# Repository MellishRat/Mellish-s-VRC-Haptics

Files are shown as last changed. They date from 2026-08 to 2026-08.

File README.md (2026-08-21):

# Mellish's VRC Haptics

ESP32 haptic-controller projects for Intiface and OscGoesBrrr. Start with the
completed two-channel build unless you specifically want to develop and test
the experimental PCA9685 design.

| Project | Status | Description |
|---|---|---|
| [Mellish Edge-Compatible Two-Motor Emulator](projects/edge-2-channel/README.md) | **Stable and verified** | Hardware-verified ESP32 build with two independent `0–20` Intiface vibration outputs on GPIO25 and GPIO26. |
| [Mellish 16-Channel Haptic Controller — Experimental](projects/mellish-16-channel/README.md) | **Experimental** | PCA9685 development area. Channels 0 and 1 map to the two currently exposed Edge-compatible outputs; custom 4–16-output Intiface support is future work. |

## Recommended starting point

Build the [stable two-channel project](projects/edge-2-channel/README.md) first.
It contains the verified firmware, wiring guidance, phone/PC connection steps,
troubleshooting notes, and the proposed `edge-2ch-v1.0.0` release notes.

The [16-channel project](projects/mellish-16-channel/README.md) is intentionally
kept separate so experimental PCA9685 work cannot be confused with the verified
direct-GPIO firmware.

## Shared images

Component reference photographs are retained in [`images/`](images/README.md).
Project-specific wiring diagrams live with each project.

## Safety

Never drive a motor directly from an ESP32 GPIO. Use a suitably rated driver or
MOSFET, a correctly rated regulated motor supply, appropriate protection, and a
common ground. Disconnect motor power before changing wiring.

## License

Licensed under the [MIT License](LICENSE).

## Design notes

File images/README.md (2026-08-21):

# Shared component photographs

These photographs are component references, not wiring diagrams. Always follow
the printed pin labels and the relevant project's wiring guide.

| Component | Photograph |
|---|---|
| ESP32-WROOM-32 development board | [esp32-wroom-32-dev-board.jpg](esp32-wroom-32-dev-board.jpg) |
| SSD1306 128×32 OLED | [ssd1306-128x32-oled.jpg](ssd1306-128x32-oled.jpg) |
| Small vibration motor module | [vibration-motor-module.jpg](vibration-motor-module.jpg) |
| DollaTek PCA9685 16-channel 12-bit PWM board | [DollaTek PCA9685 16 Channel 12-bit PWM.jpg](DollaTek%20PCA9685%2016%20Channel%2012-bit%20PWM.jpg) |

The shared editable Fritzing project is available as
[`layout.fzz`](layout.fzz). It contains the breadboard layouts for both the
stable two-channel build and the experimental 16-channel controller. Open it
with Fritzing to inspect or modify the layouts, and follow the applicable
project's wiring and safety guidance before building or applying power.

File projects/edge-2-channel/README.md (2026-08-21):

# Mellish Edge-Compatible Two-Motor Emulator

**Status: completed and hardware verified. Recommended starting point.**

This ESP32-WROOM-32 project emulates a Lovense Edge over Bluetooth Low Energy.
Its verified firmware identifies with Lovense model identifier `P`, and Intiface
exposes it as two independent vibration outputs with levels from `0` to `20`.
It is an Edge-compatible two-motor emulator; it is not described as a verified
Gemini emulator.

## Verified hardware and behaviour

- ESP32-WROOM-32 development board (`ESP32 Dev Module`)
- SSD1306 128×32 OLED at I²C address `0x3C`
- OLED SDA on GPIO21 and SCL on GPIO22
- Motor 1 control signal on GPIO25
- Motor 2 control signal on GPIO26
- `MOTOR1_MIN_PWM` = `70`
- `MOTOR2_MIN_PWM` = `75`
- OLED BLE connection status and two motor-level bars
- automatic BLE advertising restart after disconnect
- immediate motor-off disconnect failsafe
- Arduino ESP32 Core 2.x and 3.x PWM API compatibility
- two independent Intiface vibration outputs

The tested signal path is:

```text
VRChat on PC → OscGoesBrrr on PC → Intiface on phone → BLE → ESP32
```

The phone and PC communicate over the local network. The ESP32 itself uses BLE
only: it needs no Wi-Fi credentials and runs no WebSocket server.

## Build and upload

1. Install the Espressif ESP32 Arduino board package.
2. Select **ESP32 Dev Module**.
3. Install **Adafruit GFX Library** and **Adafruit SSD1306**.
4. Open [`firmware/Mellish_Edge_2_Channel/Mellish_Edge_2_Channel.ino`](firmware/Mellish_Edge_2_Channel/Mellish_Edge_2_Channel.ino).
5. Upload, then open Serial Monitor at `115200` baud.
6. Follow the [Intiface and OscGoesBrrr instructions](docs/intiface-setup.md).

The sketch folder and `.ino` filename match, as required by Arduino.

## Documentation

- [Architecture, BLE identity, and protocol](docs/architecture.md)
- [Wiring, pinout, and external motor drivers](wiring/README.md)
- [Shared editable Fritzing layouts](../../images/layout.fzz)
- [Intiface on phone and OscGoesBrrr on PC](docs/intiface-setup.md)
- [VRChat integration](docs/vrchat-setup.md)
- [Troubleshooting](docs/troubleshooting.md)
- [Hardware-verification checkpoint](docs/verified-checkpoint.md)
- [Proposed `edge-2ch-v1.0.0` release notes](docs/release-notes-edge-2ch-v1.0.0.md)

## Safety

GPIO25 and GPIO26 are control signals only. Never connect a motor directly to
an ESP32 GPIO. See the [wiring guide](wiring/README.md) before applying motor
power.

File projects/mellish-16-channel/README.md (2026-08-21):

# Mellish 16-Channel Haptic Controller — Experimental

**Status: experimental; not a replacement for the verified two-channel build.**

This development area moves motor PWM generation to a PCA9685 at I²C address
`0x40`. The PCA9685 shares the ESP32's GPIO21/GPIO22 I²C bus with the SSD1306
OLED at `0x3C`.

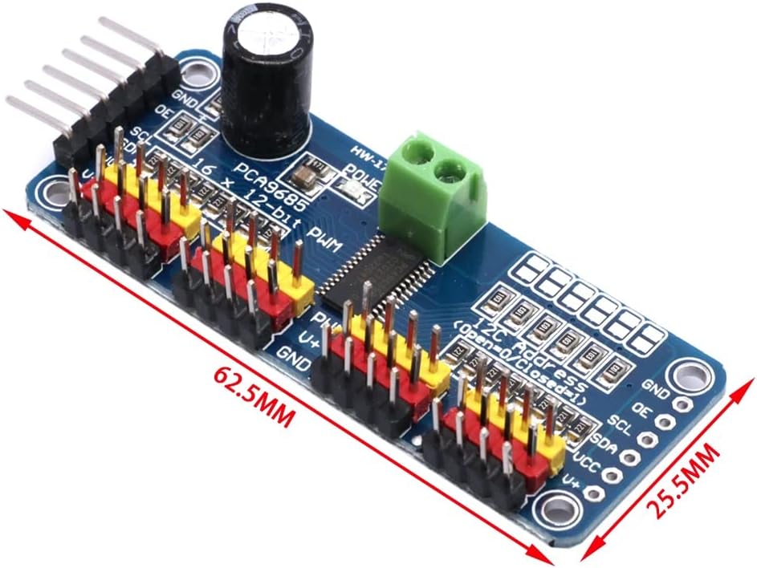
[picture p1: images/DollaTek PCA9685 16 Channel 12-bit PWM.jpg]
DollaTek PCA9685 16-channel 12-bit PWM board


The photograph is a component reference. The shared editable
[Fritzing project](../../images/layout.fzz) contains layouts for both repository
projects; select the 16-channel layout here, verify the actual board labels and the
[wiring guide](wiring/README.md) before applying power.

The current firmware still identifies as a Lovense Edge. Intiface therefore
exposes only two vibration outputs: output 0 controls PCA9685 channel 0 and
output 1 controls PCA9685 channel 1. Custom 4–16-output Intiface support is
future experimental work; channels 2–15 are not independently addressable from
Intiface yet.

## Current experimental features

- PCA9685 PWM controller at I²C address `0x40`
- SSD1306 OLED and PCA9685 sharing SDA GPIO21 and SCL GPIO22
- PCA9685 logic VCC powered from ESP32 3.3 V
- separate motor power entering at PCA9685 `V+` and `GND`
- all grounds connected in common
- Intiface outputs 0 and 1 mapped to PCA9685 channels 0 and 1
- Serial Monitor `TEST` command pulses channels 0–15 sequentially
- Serial Monitor `STOP`, Lovense `PowerOff;`, and BLE disconnect switch every channel off

## Firmware

Open
[`firmware/Mellish_16_Channel_Experimental/Mellish_16_Channel_Experimental.ino`](firmware/Mellish_16_Channel_Experimental/Mellish_16_Channel_Experimental.ino).
The sketch folder and `.ino` filename match.

Required Arduino libraries:

- Adafruit GFX Library
- Adafruit SSD1306
- Adafruit PWM Servo Driver Library
- BLE support supplied by the Espressif ESP32 Arduino core

## Documentation

- [Experimental scope and protocol](docs/architecture.md)
- [PCA9685 wiring and power guidance](wiring/README.md)
- [Shared editable Fritzing layouts](../../images/layout.fzz)
- [Development and test procedure](docs/testing.md)

For a known-good build, use the
[Mellish Edge-Compatible Two-Motor Emulator](../edge-2-channel/README.md).

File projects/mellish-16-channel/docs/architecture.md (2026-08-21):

# Experimental architecture

```text
Intiface output 0 → Lovense Vibrate1 → PCA9685 channel 0
Intiface output 1 → Lovense Vibrate2 → PCA9685 channel 1
Serial TEST command                 → channels 0–15 in sequence
```

The ESP32 currently retains the Lovense Edge BLE identity and model identifier
`P`. This deliberately preserves the established two-output Intiface path while
PCA9685 output hardware is developed. It does **not** make 16 outputs available
to Intiface. A future experimental protocol/device definition is required for
custom 4–16-output support.

The PCA9685 handles PWM for all motor-control channels. The stable project's
direct GPIO25/GPIO26 motor PWM implementation is not used in this sketch.

`STOP`, Lovense `PowerOff;`, and Bluetooth disconnect call the all-channel-off
path. BLE advertising restarts after disconnect.

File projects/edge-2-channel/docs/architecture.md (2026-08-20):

# Architecture and protocol

## Runtime architecture

```mermaid
sequenceDiagram
    participant V as VRChat (PC)
    participant O as OscGoesBrrr (PC)
    participant I as Intiface Central (phone)
    participant E as ESP32
    V->>O: OSC contact/avatar values
    O->>I: Buttplug commands via ws://phone-ip:12345
    I->>E: Lovense commands over BLE
    E->>E: Map output 0/1 to GPIO25/26 PWM
    E-->>I: DeviceType, Battery, Status responses
```

The ESP32 does not parse VRChat OSC. OGB interprets VRChat data and controls
Intiface. Intiface translates Buttplug output commands into Lovense BLE traffic.

## BLE identity

| Property | Value |
|---|---|
| Advertised name | `LVS-Edge` |
| Emulated model | Lovense Edge (`P`) |
| Stable logical address | `MELLISH-HAPTICS-001` |
| BLE service | `50300001-0023-4bd4-bbd5-a6920e4c5653` |
| Command/write characteristic | `50300002-0023-4bd4-bbd5-a6920e4c5653` |
| Response/read-notify characteristic | `50300003-0023-4bd4-bbd5-a6920e4c5653` |

The firmware uses a stable locally administered base MAC. This deliberately
differs from the address used by the earlier BLE diagnostic sketch, preventing
Android from reusing a stale bonded GATT-service cache.

## Lovense commands

| Command | Firmware behavior |
|---|---|
| `DeviceType;` | Replies `P:1:MELLISH-HAPTICS-001;` |
| `Battery;` | Replies `100;` (wired prototype placeholder) |
| `Status:1;` | Replies `2;` |
| `Vibrate1:n;` | Sets Motor 1 / GPIO25, with `n` clamped to 0–20 |
| `Vibrate2:n;` | Sets Motor 2 / GPIO26, with `n` clamped to 0–20 |
| `Vibrate:n;` | Compatibility fallback that sets both motors |
| `PowerOff;` | Stops both motors and replies `OK;` |

## Calibrated PWM mapping

Level 0 always produces PWM 0. Levels 1–20 are linearly mapped from each
motor's independent minimum usable PWM to 255.

| Lovense level | Motor 1 PWM (minimum 70) | Motor 2 PWM (minimum 75) |
|---:|---:|---:|
| 0 | 0 | 0 |
| 1 | 70 | 75 |
| 10 | 157 | 160 |
| 20 | 255 | 255 |

## Safety behavior

- Both outputs start at zero.
- BLE disconnection immediately sets both outputs to zero.
- Values are clamped to the Lovense 0–20 range.
- Each channel updates independently for `Vibrate1` and `Vibrate2`.
- The OLED is optional; failure to detect it does not disable the motor
  failsafe or Serial diagnostics.

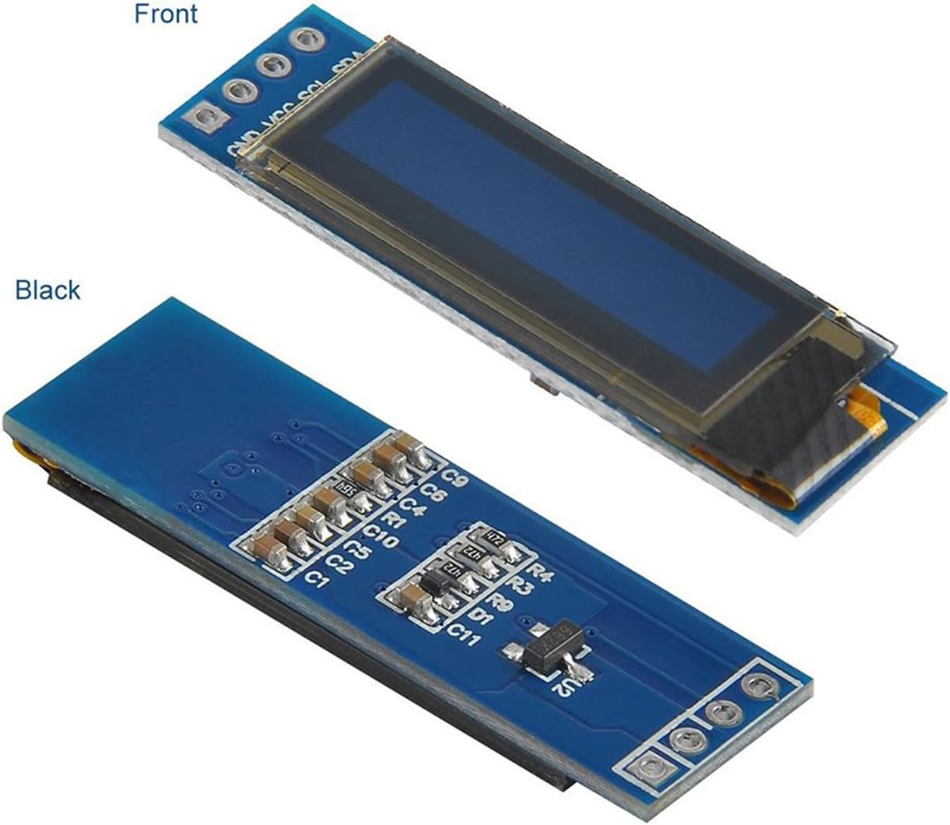
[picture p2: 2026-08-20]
images/ssd1306-128x32-oled.jpg

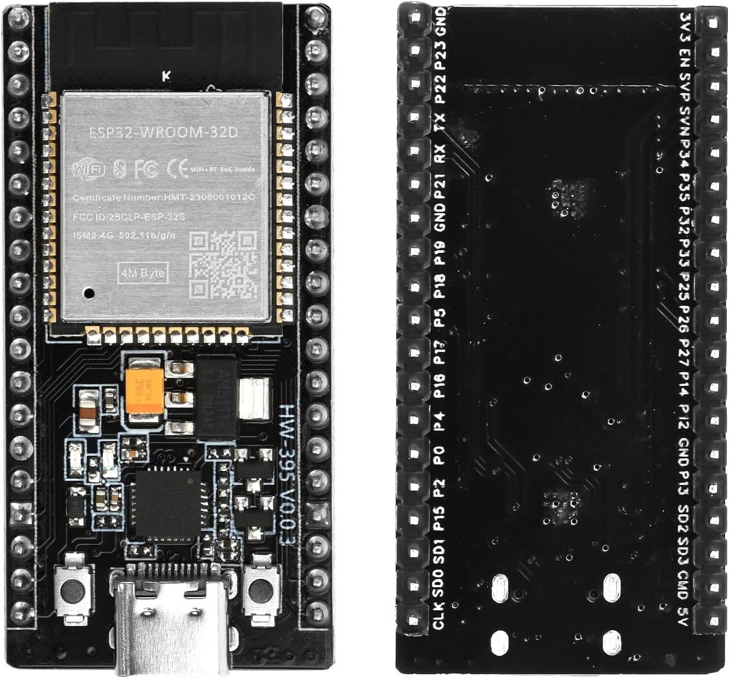
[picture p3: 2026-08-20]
images/esp32-wroom-32-dev-board.jpg

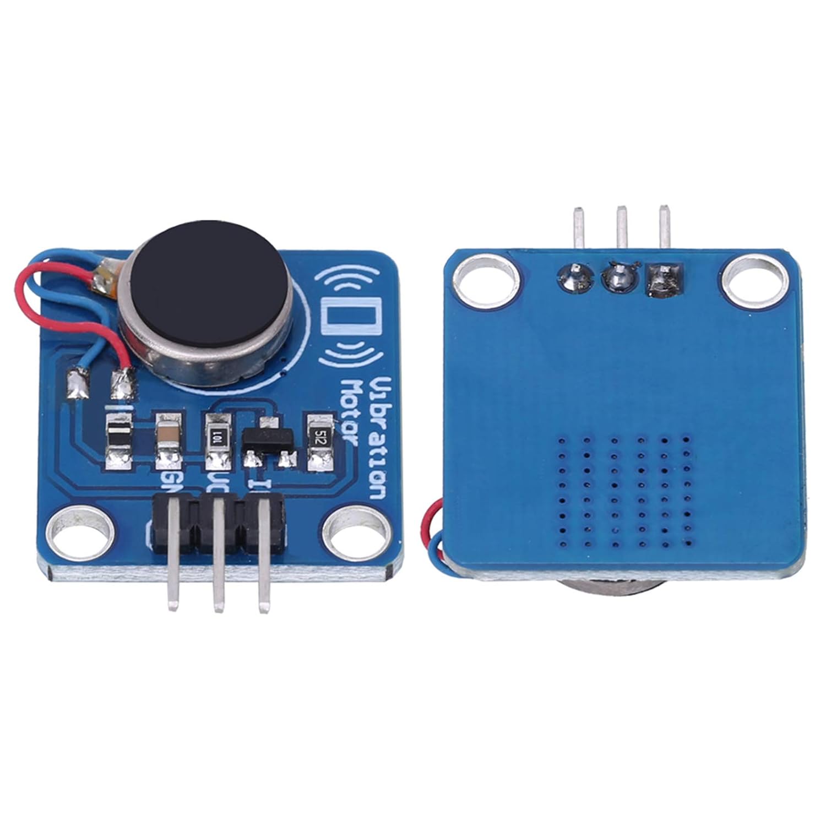
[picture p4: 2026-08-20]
images/vibration-motor-module.jpg

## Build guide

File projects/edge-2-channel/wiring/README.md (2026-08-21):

# Two-channel wiring and pinout

## Layout files

- [Open or download the shared editable Fritzing project](../../../images/layout.fzz)
- [View the rendered two-motor breadboard diagram](two-motor-breadboard.png)

The Fritzing project contains layouts for both repository projects. Select the
stable two-channel layout for this build and verify all physical pin labels
against the connection table below before applying power.

## Connections

| ESP32 connection | Destination | Purpose |
|---|---|---|
| GPIO21 | OLED SDA | I²C data |
| GPIO22 | OLED SCL | I²C clock |
| 3.3 V | OLED VCC | OLED power |
| GND | OLED GND | Common ground |
| GPIO25 | Motor 1 driver input | PWM control for Intiface output 0 |
| GPIO26 | Motor 2 driver input | PWM control for Intiface output 1 |
| GND | Both motor-driver grounds | Common signal/power reference |
| Rated motor supply + | Both driver motor-power inputs | Motor power appropriate to the motor modules |

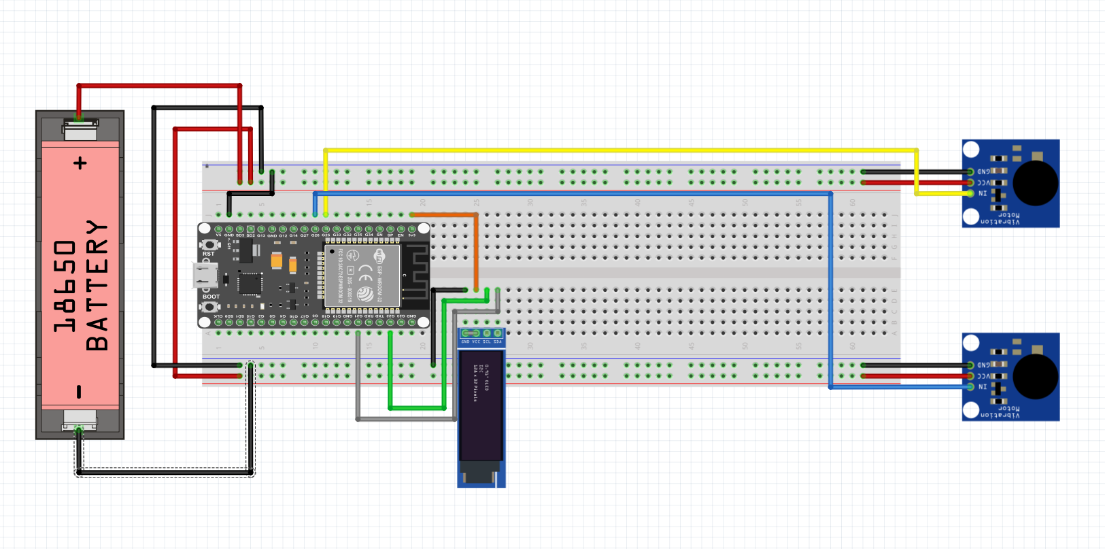
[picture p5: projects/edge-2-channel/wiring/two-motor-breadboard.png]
Two-motor breadboard wiring diagram


The diagram is a build reference; verify every physical module's printed pin
labels before applying power. Shared component photographs are in the
[repository image gallery](../../../images/README.md).

## Larger motors and external controllers

Each GPIO signal may control the logic input of a suitably rated external
MOSFET circuit or motor controller instead of the small motor module. GPIO25
and GPIO26 must remain signal connections only—never drive any motor directly
from an ESP32 GPIO.

Larger motors require their own correctly rated regulated supply, a driver with
adequate voltage/current and thermal ratings, and appropriate protection such
as flyback suppression where the chosen motor/driver requires it. Connect the
external supply ground, controller ground, and ESP32 ground together so the
control signals have a common reference. Confirm that the controller accepts
3.3 V logic.

## Electrical checks

1. Disconnect motor power before changing wiring.
2. Confirm both driver inputs accept 3.3 V logic and are active high.
3. Confirm the supply supports both motors' startup current simultaneously.
4. Join the motor-supply negative terminal to ESP32 GND.
5. Initially test each channel separately at levels `0` and `1`.
6. Stop immediately if the ESP32 resets, the OLED glitches, or anything heats.

The verified firmware uses active-high 20 kHz, 8-bit PWM.

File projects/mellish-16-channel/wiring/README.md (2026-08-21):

# PCA9685 experimental wiring

## Layout files

- [Open or download the shared editable Fritzing project](../../../images/layout.fzz)
- [View the PCA9685 component photograph](../../../images/DollaTek%20PCA9685%2016%20Channel%2012-bit%20PWM.jpg)

The Fritzing file contains layouts for both repository projects. Select the
experimental 16-channel layout here. It is an editable layout aid, not a
substitute for checking the labels and electrical ratings on the physical
modules. The textual connection table and safety requirements below are
authoritative for this project.

## I²C and logic connections

| ESP32 | OLED | PCA9685 | Purpose |
|---|---|---|---|
| 3.3 V | VCC | VCC | Logic power |
| GND | GND | GND | Common reference |
| GPIO21 | SDA | SDA | Shared I²C data |
| GPIO22 | SCL | SCL | Shared I²C clock |

- OLED address: `0x3C`
- PCA9685 address: `0x40`
- PCA9685 `VCC` must be powered from ESP32 3.3 V.
- Motor power enters through PCA9685 `V+` and `GND`, not through `VCC`.
- ESP32, OLED, PCA9685, motor supply, and motor drivers must share a common ground.

```text
ESP32 3V3 ──┬── OLED VCC
            └── PCA9685 VCC (logic)
ESP32 GND ──┬── OLED GND
            ├── PCA9685 GND
            └── regulated motor-supply negative
GPIO21 ─────┬── OLED SDA
            └── PCA9685 SDA
GPIO22 ─────┬── OLED SCL
            └── PCA9685 SCL

regulated motor-supply positive ── PCA9685 V+
PCA9685 channels 0–15 ──────────── suitable motor modules/controllers
```

## Motor modules and supply sizing

The small motor modules are specified for `3.0–5.3 V`, `60 mA` running current,
and `90 mA` starting current. Sixteen motors may demand about `1.44 A` at startup
before allowing for margin, controller losses, wiring losses, or supply
tolerance. Use a properly rated regulated supply selected for the actual motors
and simultaneous startup load.

Do not route the full 16-motor current through solderless breadboard power rails.
Use appropriately rated distribution wiring, connectors, protection, motor
drivers, and decoupling. Never drive a motor from an ESP32 GPIO or assume a bare
PCA9685 output can supply motor current; each PWM channel must feed a suitable
motor-driver or MOSFET input.

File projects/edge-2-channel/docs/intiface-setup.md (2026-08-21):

# Intiface and OscGoesBrrr setup

## Intiface on the phone

1. Start the Intiface engine.
2. Start a normal Bluetooth device scan in Intiface.
3. Wait for `LVS-Edge` to be discovered and initialized.
4. Confirm the Devices page shows a Lovense Edge with two vibration outputs.

Expected ESP32 Serial output:

```text
BLE advertising as: LVS-Edge
BLE CONNECTED to Intiface
BLE RX: DeviceType;
BLE TX: P:1:MELLISH-HAPTICS-001;
```

Android's normal Bluetooth settings may not list this BLE-only peripheral. The
Intiface scan is authoritative. Do not manually bond the ESP32.

The ESP32 connects only by BLE. It does not need the phone's IP address, Wi-Fi
credentials, or any custom WebSocket-device entry.

## OscGoesBrrr on the PC

With Intiface running on the phone, configure OGB to connect to the phone's LAN
address, for example:

```text
ws://192.168.0.251:12345
```

The actual phone IP can change with DHCP. The ESP32 does not use this address;
only OGB needs it. The verified test used OscGoesBrrr v2.1.28.

## First output test

Before involving VRChat:

1. Set both outputs to 0.
2. Exercise output 0 through `0 → 1 → 10 → 20 → 0`; Motor 2 must remain still.
3. Exercise output 1 through the same sequence; Motor 1 must remain still.
4. Disconnect Intiface and confirm both motors stop immediately.

Expected PWM values are documented in [architecture.md](architecture.md).

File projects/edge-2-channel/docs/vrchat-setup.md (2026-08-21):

# VRChat integration

First confirm the completed two-channel build using Intiface's independent
output controls, then configure the VRChat-specific mapping.

## Planned data path

```text
VRCFury/SPS Touch Zones → VRChat OSC → OscGoesBrrr → Intiface → BLE ESP32
```

Use VRCFury SPS Touch Zones with OGB IDs such as `VB01` and `VB02`. OGB should
map those sources to the two features of the single Edge-compatible device:

```text
VB01 → output 0 → GPIO25 → Motor 1
VB02 → output 1 → GPIO26 → Motor 2
```

The firmware intentionally has no knowledge of body-part names. All semantic
mapping belongs in the avatar/OGB configuration.

The BLE device, two Intiface outputs, and independent physical motor response
are hardware verified. OGB IDs and avatar contact placement are configured per
avatar and are not embedded in the firmware.

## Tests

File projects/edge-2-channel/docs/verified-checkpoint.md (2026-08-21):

# Hardware-verified checkpoint — 20 August 2026

## Verified

- ESP32-WROOM-32 uploads and runs from the Arduino IDE.
- SSD1306 128×32 OLED works on GPIO21/GPIO22 at `0x3C`.
- GPIO25 and GPIO26 independently control the two motor driver modules.
- ESP32 Bluetooth radio advertising and GATT connection work.
- Intiface on Android discovers `LVS-Edge` over BLE.
- Intiface identifies it as a Lovense Edge.
- The device populates in Intiface with two vibration outputs.
- Intiface controls the two physical motors independently across the `0–20` range.
- Motor 1 has a verified minimum PWM of `70`; Motor 2 has a verified minimum PWM of `75`.
- OGB v2.1.28 connects from the PC to Intiface on the phone over the LAN.
- BLE disconnect invokes the firmware motor-off failsafe.

The ESP32/Intiface two-channel build is complete and hardware verified. Avatar
contact placement and OscGoesBrrr source bindings remain user-specific setup,
not unverified firmware behaviour.

## Important diagnostic result

The initial BLE radio test and haptics firmware shared a Bluetooth address,
causing Android to reuse the diagnostic sketch's cached GATT table. The current
firmware assigns a separate stable locally administered base MAC, ensuring that
Android discovers the correct Lovense service and characteristics.

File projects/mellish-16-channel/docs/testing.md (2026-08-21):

# Experimental test procedure

1. Disconnect motor power and verify the wiring against the
   [PCA9685 wiring guide](../wiring/README.md).
2. Upload the experimental sketch and open Serial Monitor at `115200` baud.
3. Confirm the OLED is found at `0x3C` and the PCA9685 at `0x40`.
4. With a current-limited, correctly rated motor supply connected to `V+` and
   `GND`, enter `TEST` in Serial Monitor.
5. Confirm channels 0 through 15 pulse one at a time and return off.
6. Enter `STOP` at any time to switch every channel off.
7. In Intiface, confirm output 0 affects only PCA9685 channel 0 and output 1
   affects only channel 1.
8. Disconnect Bluetooth and confirm all channels switch off immediately.

The `TEST` command is a bench diagnostic, not an Intiface 16-output interface.

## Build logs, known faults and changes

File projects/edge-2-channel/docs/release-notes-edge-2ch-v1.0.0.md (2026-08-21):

# Proposed release notes: `edge-2ch-v1.0.0`

> Proposed only. No release or Git tag has been created.

## Mellish Edge-Compatible Two-Motor Emulator v1.0.0

First stable, hardware-verified release of the two-channel ESP32 haptic controller.

### Highlights

- Lovense Edge BLE emulation using model identifier `P`
- two independent Intiface `0–20` vibration outputs
- GPIO25 Motor 1 and GPIO26 Motor 2 PWM control
- independent calibrated minimum PWM values of `70` and `75`
- SSD1306 128×32 OLED status and motor-level bars on GPIO21/GPIO22 at `0x3C`
- automatic advertising restart after BLE disconnect
- immediate all-motors-off disconnect failsafe
- Arduino ESP32 Core 2.x/3.x PWM compatibility
- documented Intiface-on-phone and OscGoesBrrr-on-PC workflow

### Hardware safety

Motors must be driven through suitable motor-driver modules, MOSFET circuits,
or controllers. Never drive a motor directly from an ESP32 GPIO. Use a
correctly rated supply, appropriate protection, and a common ground.

### Release approval

Create the `edge-2ch-v1.0.0` tag and GitHub release only after explicit owner approval.

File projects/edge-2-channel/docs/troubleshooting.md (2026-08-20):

# Troubleshooting

## Intiface sees `LVS-Edge` in logs but it is absent from Devices

Discovery is not the same as initialization. Check Serial Monitor for
`BLE CONNECTED` followed by `DeviceType;`. Leave the scan running long enough
for initialization and ensure no other app is connected to the ESP32.

## nRF Connect shows an old `12345678...` service

That UUID belongs to the temporary BLE radio-test sketch. Android has cached the
old GATT table. The current firmware uses a separate stable base MAC to avoid
that cache. Upload the latest firmware, reset the ESP32, and select the newly
advertised address. Do not bond it.

## `btleplug error: NotConnected`

- Close nRF Connect completely; only one client can hold the BLE connection.
- Remove any old ESP32 test bond.
- Toggle phone Bluetooth off and on, then reset the ESP32.
- Confirm a dedicated BLE scan sees `LVS-Edge` and service `50300001...`.

## OLED remains blank

Confirm address `0x3C`, SDA GPIO21, SCL GPIO22, 3.3 V, and common ground. The
firmware continues safely without the display and reports the failure over
Serial at 115200 baud.

## Motor does not start at level 1

Increase only that channel's minimum in steps of about five:

```cpp
const uint8_t MOTOR1_MIN_PWM = 70;
const uint8_t MOTOR2_MIN_PWM = 75;
```

Repeat `0 → 1 → 0` five to ten times. Do not change the other channel. Confirm
the other motor remains physically still and its OLED/Serial level remains 0.

## Motor is always on

Disconnect motor power. Verify `IN`, `VCC`, and `GND`, and confirm the driver is
active high. Do not compensate for incorrect wiring in software.

## ESP32 resets or OLED flickers when motors start

Treat this as a power-integrity or motor-noise problem. Use a correctly sized
supply, common ground, short wiring, and appropriate decoupling/suppression.

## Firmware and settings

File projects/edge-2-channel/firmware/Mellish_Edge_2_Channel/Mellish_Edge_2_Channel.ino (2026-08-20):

/*
  Mellish VRC Haptics - ESP32 Lovense Edge BLE test firmware

  Intiface on the phone discovers this ESP32 during a normal Bluetooth scan.
  No ESP32 Wi-Fi settings or custom WebSocket-device entry are required.

  Hardware: SSD1306 128x32 (SDA 21, SCL 22, 0x3C), Motor 1 GPIO25,
  Motor 2 GPIO26. Drive motors through suitable driver modules with common GND.

  Libraries: Adafruit SSD1306 and Adafruit GFX. BLE support is included in the
  Arduino ESP32 board package. Board profile: ESP32 Dev Module.
*/

#include <Wire.h>
#include <Adafruit_GFX.h>
#include <Adafruit_SSD1306.h>
#include <BLEDevice.h>
#include <BLEServer.h>
#include <BLEUtils.h>
#include <BLE2902.h>
#include <esp_system.h>
#if __has_include(<esp_mac.h>)
  #include <esp_mac.h>
#else
  #include <esp_err.h>
  extern "C" esp_err_t esp_base_mac_addr_set(const uint8_t* mac);
#endif
#if __has_include(<esp_arduino_version.h>)
  #include <esp_arduino_version.h>
#endif

// Keep the Lovense-compatible name in the primary advertisement. The service
// UUID is placed in the scan response, matching the verified BLE radio test.
const char* BLE_DEVICE_NAME = "LVS-Edge";
const char* DEVICE_ADDRESS  = "MELLISH-HAPTICS-001";

// Use a stable, locally administered address that differs from the address
// used by the earlier BLE radio-test sketch. This prevents Android from
// reusing that sketch's bonded GATT service cache.
uint8_t HAPTICS_BASE_MAC[6] = {0x32, 0x4D, 0x56, 0x48, 0x01, 0x01};

// Lovense P/Edge-family BLE UART service. Intiface writes commands to 0002
// and subscribes to responses from 0003.
#define LOVENSE_SERVICE_UUID "50300001-0023-4bd4-bbd5-a6920e4c5653"
#define LOVENSE_TX_UUID      "50300002-0023-4bd4-bbd5-a6920e4c5653"
#define LOVENSE_RX_UUID      "50300003-0023-4bd4-bbd5-a6920e4c5653"

constexpr uint8_t OLED_SDA = 21, OLED_SCL = 22, OLED_ADDRESS = 0x3C;
constexpr uint8_t MOTOR1_PIN = 25, MOTOR2_PIN = 26;
const uint8_t MOTOR1_MIN_PWM = 70;
const uint8_t MOTOR2_MIN_PWM = 75;
constexpr uint32_t PWM_FREQUENCY = 20000;
constexpr uint8_t PWM_RESOLUTION = 8;
constexpr uint8_t MOTOR1_CHANNEL = 0, MOTOR2_CHANNEL = 1; // Core 2.x

Adafruit_SSD1306 display(128, 32, &Wire, -1);
BLECharacteristic* responseCharacteristic = nullptr;
volatile bool bleConnected = false, restartAdvertising = false;
volatile bool displayDirty = true;
volatile uint8_t motor1Level = 0, motor2Level = 0;
bool oledAvailable = false;
unsigned long lastDisplayUpdate = 0;

void writeMotor1(uint8_t pwm) {
#if defined(ESP_ARDUINO_VERSION_MAJOR) && ESP_ARDUINO_VERSION_MAJOR >= 3
  ledcWrite(MOTOR1_PIN, pwm);
#else
  ledcWrite(MOTOR1_CHANNEL, pwm);
#endif
}

void writeMotor2(uint8_t pwm) {
#if defined(ESP_ARDUINO_VERSION_MAJOR) && ESP_ARDUINO_VERSION_MAJOR >= 3
  ledcWrite(MOTOR2_PIN, pwm);
#else
  ledcWrite(MOTOR2_CHANNEL, pwm);
#endif
}

uint8_t lovenseToPWM(int level, uint8_t minimumPWM) {
  level = constrain(level, 0, 20);
  return level == 0 ? 0 : (uint8_t)map(level, 1, 20, minimumPWM, 255);
}

void setMotor1Level(int level) {
  level = constrain(level, 0, 20);
  motor1Level = (uint8_t)level;
  uint8_t pwm = lovenseToPWM(level, MOTOR1_MIN_PWM);
  writeMotor1(pwm);
  displayDirty = true;
  Serial.printf("Motor 1: Level=%d PWM=%u Min=%u\n", level, pwm, MOTOR1_MIN_PWM);
}

void setMotor2Level(int level) {
  level = constrain(level, 0, 20);
  motor2Level = (uint8_t)level;
  uint8_t pwm = lovenseToPWM(level, MOTOR2_MIN_PWM);
  writeMotor2(pwm);
  displayDirty = true;
  Serial.printf("Motor 2: Level=%d PWM=%u Min=%u\n", level, pwm, MOTOR2_MIN_PWM);
}

void stopAllMotors() { setMotor1Level(0); setMotor2Level(0); }

void setupPWM() {
#if defined(ESP_ARDUINO_VERSION_MAJOR) && ESP_ARDUINO_VERSION_MAJOR >= 3
  if (!ledcAttach(MOTOR1_PIN, PWM_FREQUENCY, PWM_RESOLUTION))
    Serial.println("ERROR: PWM attach failed on GPIO25");
  if (!ledcAttach(MOTOR2_PIN, PWM_FREQUENCY, PWM_RESOLUTION))
    Serial.println("ERROR: PWM attach failed on GPIO26");
#else
  ledcSetup(MOTOR1_CHANNEL, PWM_FREQUENCY, PWM_RESOLUTION);
  ledcSetup(MOTOR2_CHANNEL, PWM_FREQUENCY, PWM_RESOLUTION);
  ledcAttachPin(MOTOR1_PIN, MOTOR1_CHANNEL);
  ledcAttachPin(MOTOR2_PIN, MOTOR2_CHANNEL);
#endif
  writeMotor1(0); writeMotor2(0);
}

void drawBar(int x, int y, uint8_t level) {
  display.drawRect(x, y, 76, 8, SSD1306_WHITE);
  int fill = map(constrain(level, 0, 20), 0, 20, 0, 74);
  if (fill) display.fillRect(x + 1, y + 1, fill, 6, SSD1306_WHITE);
}

void updateDisplay(bool force = false) {
  if (!oledAvailable) return;
  if (!force && !displayDirty && millis() - lastDisplayUpdate < 500) return;
  if (!force && millis() - lastDisplayUpdate < 100) return;
  lastDisplayUpdate = millis(); displayDirty = false;
  uint8_t m1 = motor1Level, m2 = motor2Level;
  display.clearDisplay(); display.setTextSize(1); display.setTextColor(SSD1306_WHITE);
  display.setCursor(0, 0);
  display.print(bleConnected ? "Lovense Edge: READY" : "BLE: WAITING/SCAN");
  display.setCursor(0, 10); display.print("M1"); drawBar(18, 10, m1);
  display.setCursor(99, 10); if (m1 < 10) display.print(' '); display.print(m1);
  display.setCursor(0, 22); display.print("M2"); drawBar(18, 22, m2);
  display.setCursor(99, 22); if (m2 < 10) display.print(' '); display.print(m2);
  display.display();
}

void sendResponse(const String& response) {
  if (!responseCharacteristic || !bleConnected || !response.length()) return;
  responseCharacteristic->setValue((uint8_t*)response.c_str(), response.length());
  responseCharacteristic->notify();
  Serial.print("BLE TX: "); Serial.println(response);
}

bool extractLevel(const String& command, int& level) {
  int colon = command.indexOf(':'), semi = command.indexOf(';', colon + 1);
  if (colon < 0 || semi <= colon + 1) return false;
  level = constrain(command.substring(colon + 1, semi).toInt(), 0, 20);
  return true;
}

void processCommand(String command) {
  command.trim(); if (!command.length()) return;
  Serial.print("BLE RX: "); Serial.println(command);
  if (command == "DeviceType;") {
    String response = "P:1:"; response += DEVICE_ADDRESS; response += ';';
    sendResponse(response); return;
  }
  if (command == "Battery;") { sendResponse("100;"); return; }
  if (command == "Status:1;") { sendResponse("2;"); return; }
  int level = 0;
  if (command.startsWith("Vibrate1:") && extractLevel(command, level)) {
    setMotor1Level(level); return;
  }
  if (command.startsWith("Vibrate2:") && extractLevel(command, level)) {
    setMotor2Level(level); return;
  }
  if (command.startsWith("Vibrate:") && extractLevel(command, level)) {
    setMotor1Level(level); setMotor2Level(level); return;
  }
  if (command == "PowerOff;") { stopAllMotors(); sendResponse("OK;"); return; }
  Serial.print("Unhandled Lovense command: "); Serial.println(command);
}

void processPayload(const uint8_t* data, size_t length) {
  if (!data || !length) return;
  String payload; payload.reserve(length + 1);
  for (size_t i = 0; i < length; ++i) payload += (char)data[i];
  int start = 0;
  while (start < payload.length()) {
    int semi = payload.indexOf(';', start);
    if (semi < 0) {
      String remainder = payload.substring(start); remainder.trim();
      if (remainder.length()) { Serial.print("Incomplete BLE command: "); Serial.println(remainder); }
      break;
    }
    processCommand(payload.substring(start, semi + 1)); start = semi + 1;
  }
}

class WriteCallbacks : public BLECharacteristicCallbacks {
  void onWrite(BLECharacteristic* characteristic) override {
    processPayload(characteristic->getData(), characteristic->getLength());
  }
};

class ServerCallbacks : public BLEServerCallbacks {
  void onConnect(BLEServer*) override {
    bleConnected = true; displayDirty = true;
    Serial.println("BLE CONNECTED to Intiface");
  }
  void onDisconnect(BLEServer*) override {
    bleConnected = false; restartAdvertising = true; displayDirty = true;
    stopAllMotors(); Serial.println("BLE DISCONNECTED - motors stopped");
  }
};

void setupBLE() {
  esp_base_mac_addr_set(HAPTICS_BASE_MAC);
  BLEDevice::init(BLE_DEVICE_NAME);
  BLEServer* server = BLEDevice::createServer();
  server->setCallbacks(new ServerCallbacks());
  BLEService* service = server->createService(LOVENSE_SERVICE_UUID);
  BLECharacteristic* commands = service->createCharacteristic(
    LOVENSE_TX_UUID, BLECharacteristic::PROPERTY_WRITE | BLECharacteristic::PROPERTY_WRITE_NR);
  commands->setCallbacks(new WriteCallbacks());
  responseCharacteristic = service->createCharacteristic(
    LOVENSE_RX_UUID, BLECharacteristic::PROPERTY_READ | BLECharacteristic::PROPERTY_NOTIFY);
  responseCharacteristic->addDescriptor(new BLE2902());
  service->start();
  BLEAdvertising* advertising = BLEDevice::getAdvertising();
  BLEAdvertisementData advertisementData;
  advertisementData.setFlags(0x06); // General discoverable, no classic BT.
  advertisementData.setName(BLE_DEVICE_NAME);
  advertising->setAdvertisementData(advertisementData);

  BLEAdvertisementData scanResponse;
  scanResponse.setCompleteServices(BLEUUID(LOVENSE_SERVICE_UUID));
  advertising->setScanResponseData(scanResponse);
  BLEDevice::startAdvertising();
  Serial.print("BLE advertising as: "); Serial.println(BLE_DEVICE_NAME);
  Serial.println("Start a normal device scan in Intiface on the phone.");
}

void setup() {
  Serial.begin(115200); delay(300);
  Serial.println("\nMellish VRC Haptics - Lovense Edge BLE Test");
  pinMode(MOTOR1_PIN, OUTPUT); pinMode(MOTOR2_PIN, OUTPUT);
  setupPWM(); stopAllMotors();
  Wire.begin(OLED_SDA, OLED_SCL);
  oledAvailable = display.begin(SSD1306_SWITCHCAPVCC, OLED_ADDRESS);
  if (!oledAvailable) Serial.println("WARNING: SSD1306 OLED not detected at 0x3C");
  else {
    display.clearDisplay(); display.setTextSize(1); display.setTextColor(SSD1306_WHITE);
    display.setCursor(0, 0); display.println("Mellish VRC Haptics");
    display.println("Starting BLE..."); display.display();
  }
  setupBLE(); updateDisplay(true);
}

void loop() {
  if (restartAdvertising) {
    restartAdvertising = false; delay(250); BLEDevice::startAdvertising();
    Serial.println("BLE advertising restarted");
  }
  updateDisplay(); delay(5);
}
